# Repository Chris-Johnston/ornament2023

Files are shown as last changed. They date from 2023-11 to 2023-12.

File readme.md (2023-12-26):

# Xmas Ornament 2023

An ATTiny404 LED Xmas tree ornament.

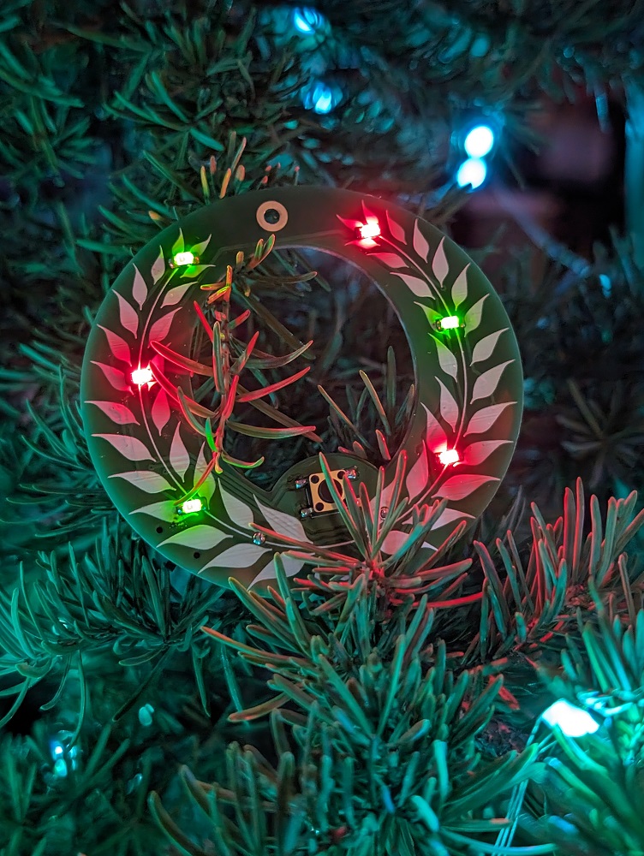
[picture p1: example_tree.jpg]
An image of the board in a tree


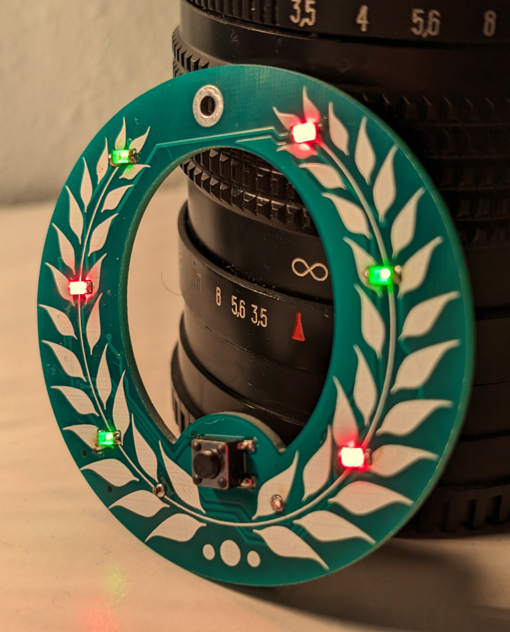
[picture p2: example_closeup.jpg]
Another image of the board closeup


This year I waited until the last minute,
[and so this design is very derivative of last year's design.](https://github.com/Chris-Johnston/ornament2022)

## Resources used

- [svg2mod] was used to generate the footprint of the board, and the front silkscreen layer
  - I licensed a stock image for the front layer silkscreen
- I referred to [SerialUPDI] again as reference for getting UPDI working (and used the same adapter board from last year, apparently I had swapped +5V and GND somehow!?)
- [megaTinyCore] was used with Arduino (via the vscode Arduino extension) to upload to the ATTiny404

[svg2mod]: https://github.com/svg2mod/svg2mod
[SerialUPDI]: https://teddywarner.org/Projects/SerialUPDI/
[megaTinyCore]: https://github.com/SpenceKonde/megaTinyCore

## Bill of Materials

| Reference | Description | Part No. | Price |
| --- | --- | --- | ----- |
| PCB | | | $0.53 (+ $0.80 shipping because I did this late) |
| C1 | 1 uf 1206 capacitor | CL31B105KAHNNNE | $0.0534 |
| D1 - D6 | 1206 Bidirectional Red/Green LED | XZMDKVG55W-4 | $1.10 (0.1835 ea.) |
| R1 - R6 | 1206 47 ohm resistor | WR12X470 JTL | $0.06 ($0.0112 ea.)
| SW1 | 6x6mm Pushbutton | Generic | $0.05 |
| SW2 | Slide Switch | JS102011SAQN | $0.65 |
| U1 | Attiny404 | Attiny404-SSN | $0.59 |
| B1 | CR2023 Battery Holder | BH-25C-1 | $0.0785 |

Unit cost w/o shipping: $3.11

## Changes from last year's version

In 2021 I made [snowflake-ornament] and [2022 I made a tree ornament.](https://github.com/Chris-Johnston/ornament2022) This year doesn't have
many changes, other than a different footprint and one less LED.

One less LED fits better with this board layout, and also means that
each common I/O between the left and right side can use PWM.
Despite this, I didn't actually have time to implement anything which
uses the PWM, I was finishing the code the same day I was supposed to drop these off.

Since this was so rushed, the board layout had a few quirks and features. All of the LEDs but ONE face the same orientation,
and the back isn't very symmetric.
For the most part it all worked though.

[snowflake-ornament]: https://github.com/Chris-Johnston/snowflake-ornament

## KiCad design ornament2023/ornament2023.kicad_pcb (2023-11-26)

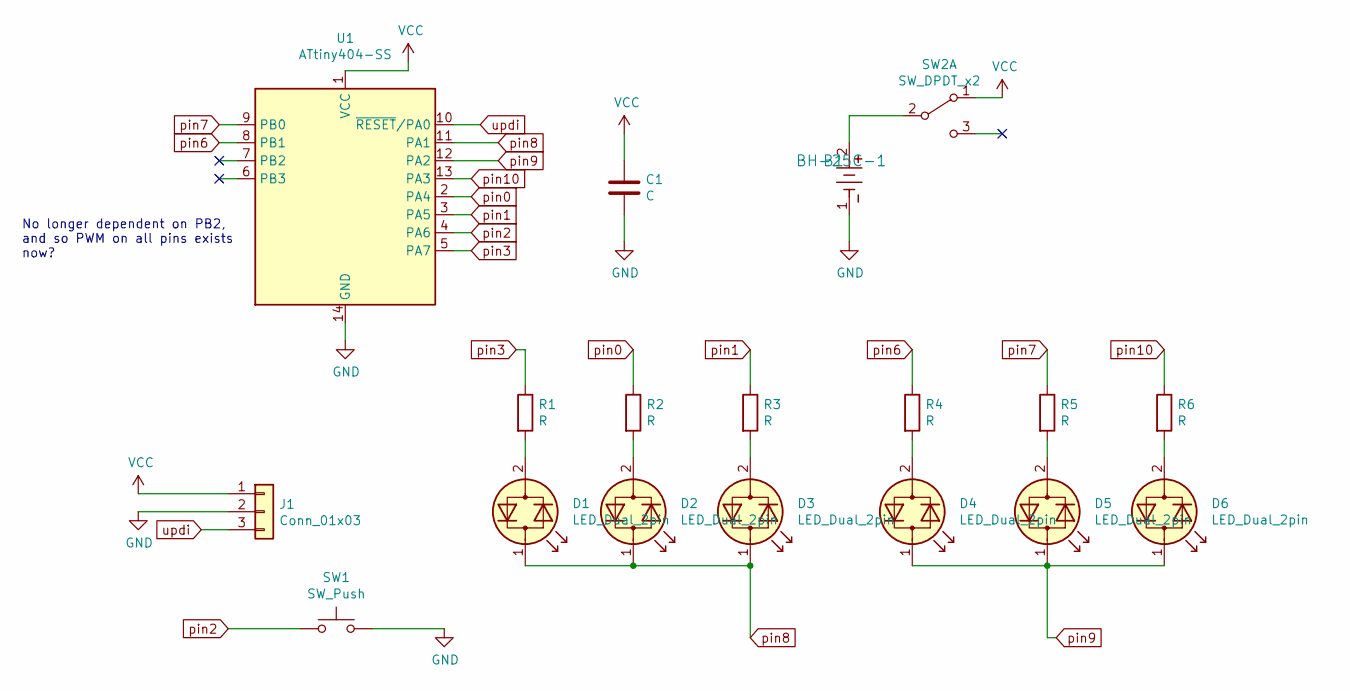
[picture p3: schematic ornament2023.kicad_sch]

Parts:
B1: BH-25C-1; BH-25C-1_ADM
C1: C; C_1206_3216Metric_Pad1.42x1.75mm_HandSolder
D1, D2, D3, D4, D5, D6: LED_Dual_2pin; Custom_LessSilkscreenLED_1206_3216Metric_Pad1.42x1.75mm_Han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
J1: Conn_01x03; custom_updipad_PinHeader_1x03_P2.54mm_Vertical
R1, R2, R3, R4, R5, R6: R; R_1206_3216Metric_Pad1.42x1.75mm_HandSolder
SW1: SW_Push; SW_Push_1P1T_NO_6x6mm_H9.5mm
SW2: SW_DPDT_x2; SW_SPDT_CK-JS102011SAQN
U1: ATtiny404-SS; SOIC-14_3.9x8.7mm_P1.27mm

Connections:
GND: B1.1, C1.2, J1.2, SW1.2, U1.14 (GND)
unnamed: D1.2 (AK), R1.2
unnamed: D2.2 (AK), R2.2
unnamed: D3.2 (AK), R3.2
unnamed: D4.2 (AK), R4.2
unnamed: D5.2 (AK), R5.2
unnamed: D6.2 (AK), R6.2
unnamed: B1.2, SW2.2 (B)
VCC: C1.1, J1.1, SW2.1 (A), U1.1 (VCC)
pin0: R2.1, U1.2 (PA4)
pin1: R3.1, U1.3 (PA5)
pin2: SW1.1, U1.4 (PA6)
pin3: R1.1, U1.5 (PA7)
pin6: R4.1, U1.8 (PB1)
pin7: R5.1, U1.9 (PB0)
pin8: D1.1 (KA), D2.1 (KA), D3.1 (KA), U1.11 (PA1)
pin9: D4.1 (KA), D5.1 (KA), D6.1 (KA), U1.12 (PA2)
pin10: R6.1, U1.13 (PA3)
updi: J1.3, U1.10 (~RESET/PA0)

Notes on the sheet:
No longer dependent on PB2, and so PWM on all pins exists now?

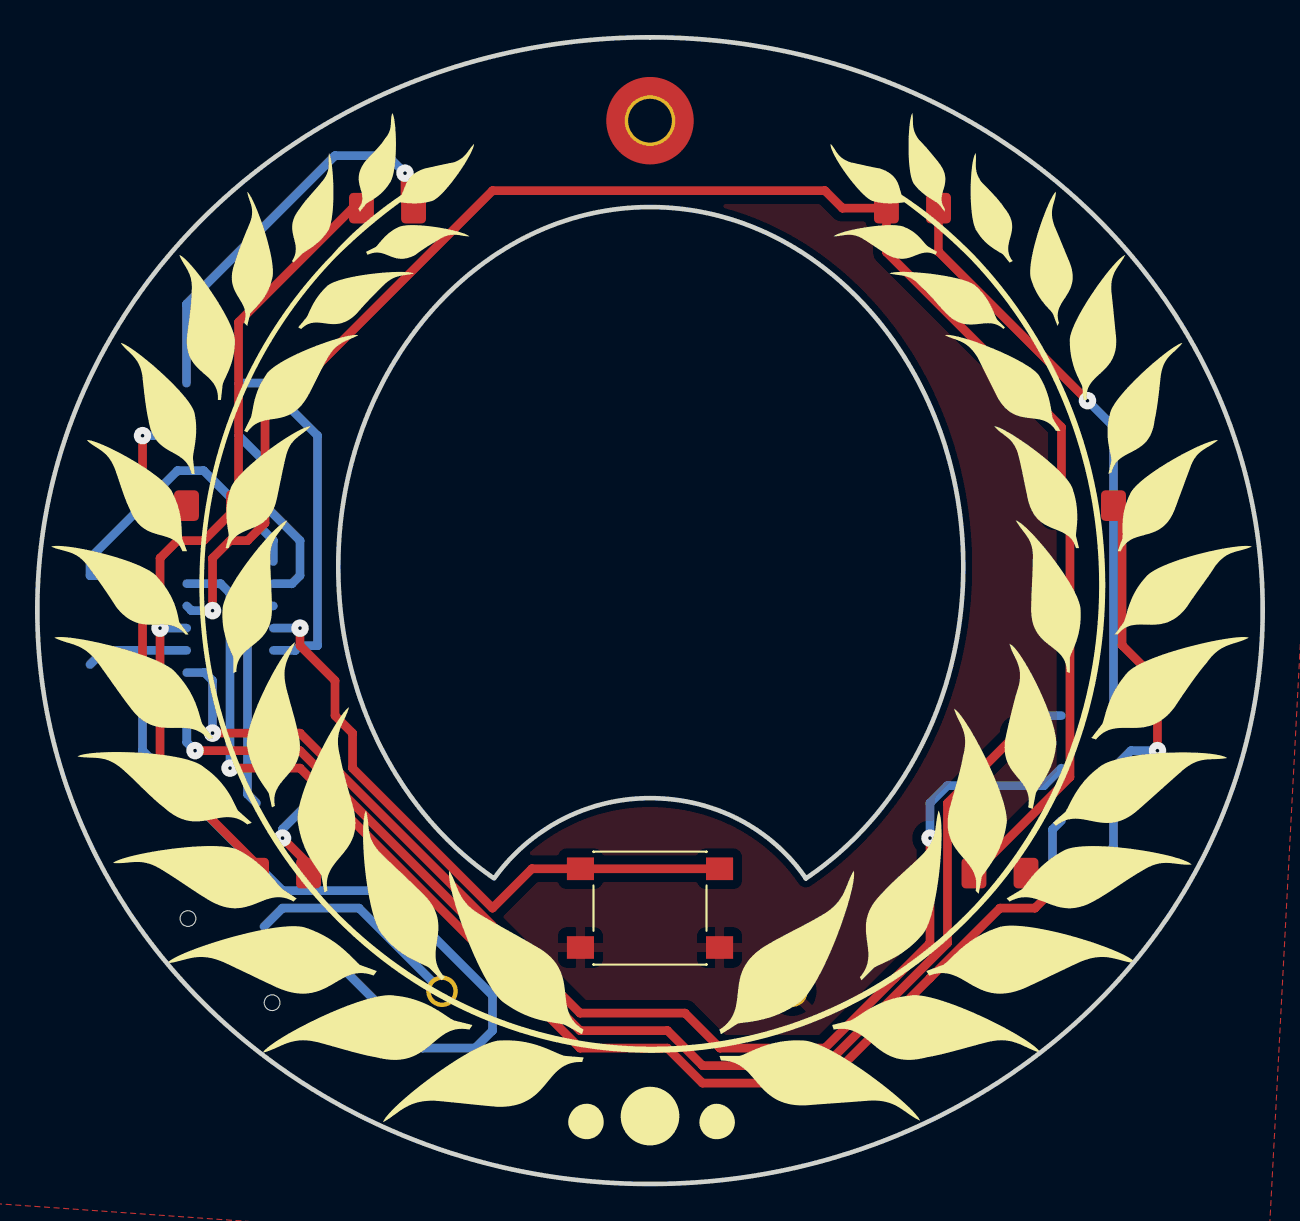
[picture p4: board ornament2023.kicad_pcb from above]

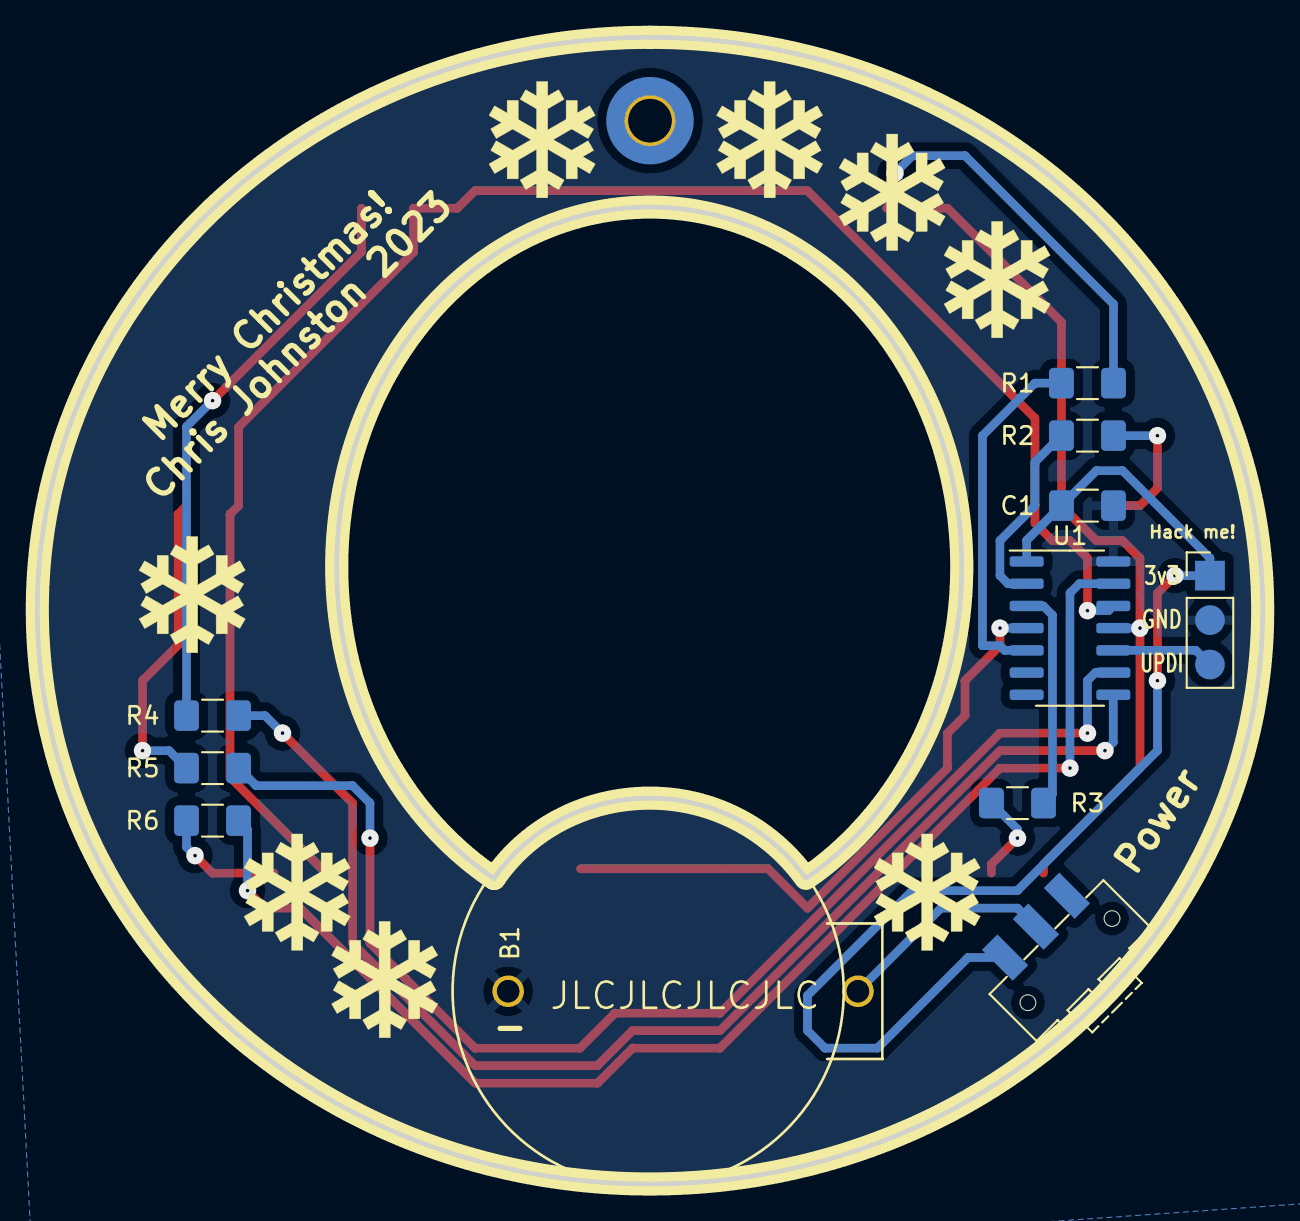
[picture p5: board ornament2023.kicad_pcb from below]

Board: 2 copper layers, 70.0 x 65.5 mm, 27 parts (19 on the bottom side), 19 nets.

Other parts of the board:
svg2mod: G***; wreath
svg2mod#2, svg2mod#3, svg2mod#4, svg2mod#5, svg2mod#6, svg2mod#7, svg2mod#8, svg2mod#9: G***; Snow_flake2

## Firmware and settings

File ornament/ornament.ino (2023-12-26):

// I never said this code wouldn't be messy.
// Merry Christmas.

#include <avr/io.h>
// #include <avr/iotn404.h>
#include <avr/interrupt.h>

int pinMin = 0;
int pinMax = 6;

// pinList - goes clockwise from the top
int pinlist[] = {
  // right side
  6, 7, 10,
  // left side
  1, 0, 3
};

int topCommon = 8; // left
int bottomCommon = 9; // right

// forward direction (0) is red (write 1 on pos)
// otherwise green
int topColor = 0;
int bottomColor = 0;

// pin with the button
int buttonIn = 2; // PA6
#define PIN_BUTTON 2
#define DEBOUNCE_TIME 150
#define NUM_PATTERNS 10

unsigned long lastDebounceTime = 0;
unsigned long button_debounce = 0;

int pattern = 0;

// the setup function runs once when you press reset or power the board
void setup() {
  // common
  pinMode(topCommon, OUTPUT);
  pinMode(bottomCommon, OUTPUT);

  for (int i = pinMin; i < pinMax; i++)
  {
    pinMode(pinlist[i], OUTPUT);
  }
  pinMode(buttonIn, INPUT_PULLUP);

  // enable PCINT0_vect for pin change
  PORTA.PIN6CTRL |= PORT_ISC_FALLING_gc;
}

// these show alternating colors
void xmascolors()
{
  int colorcycle = millis() / 1500 % 2;
  for (int p = 0; p < pinMax; p++)
  {
    digitalWrite(pinlist[p], (p + colorcycle) % 2 == 1);
  }

  // static
  // digitalWrite(topCommon, colorcycle);
  // digitalWrite(bottomCommon, colorcycle);

  // alternate the colors quickly
  for (int i = 0; i < 100; i++)
  {
    digitalWrite(topCommon, colorcycle);
    digitalWrite(bottomCommon, colorcycle);
    
    delay(1);

    digitalWrite(topCommon, 1 ^ colorcycle);
    digitalWrite(bottomCommon, 1 ^ colorcycle);

    delay(1);
  }
}

void loop()
{
  // handleDebounce();

  switch (pattern)
  {
    // case 0:
    //   // cycle();
    //   // off();
    //   break;
    // case 1:
    //   // too bright
    //   // topColor = 1;
    //   // bottomColor = 1;
    //   // solid();
    //   break;
    case 0:
      // testPattern();
      xmascolors();
      // wipeDown();
      // solid is tooo bright
      // topColor = 0;
      // bottomColor = 0;
      // solid();
      break;
    case 1:
      blonk();
      break;
    case 2:
      // may break if I end up using different resistors
      dimGreen();
      break;
    case 3:
      dimRed();
      break;
    case 4:
      orange();
      break;
    case 5:
      clockButNot();
      break;
    case 6:
      wipeDown();
      break;
    default:
      pattern = 0;
      break;
  }
}

ISR(PORTA_PORT_vect)
{
    // only update pattern if less than debounce time
    auto time = millis();
    if ((time - button_debounce) > DEBOUNCE_TIME)
    {
        pattern = (pattern + 1) % NUM_PATTERNS;

        button_debounce = millis();
    }

    // Have to manually clear the interrupt flag
    VPORTA.INTFLAGS |= (1 << 6);
}

void cycle() // too bright
{
  // cycle through the pwm pins randomly
  int pinIdx = random(1, pinMax);
  int color = random(1024) % 2;
  // int color = 0;
  bottomColor = color;
  topColor = color;

  off();

  for (int i = 0; i < 200; i+= 1)
  {
    analogWrite(pinlist[pinIdx], i);
    delay(1);
  }

  off();

  delay(50);
}

int wipeDownIdx = 0;
void wipeDown()
{
  {
    if (wipeDownIdx == 0)
    {
      bottomColor ^= 1;
    }
    topColor = bottomColor;
    off();
    
    digitalWrite(pinlist[wipeDownIdx], bottomColor ^ 1);
    // delayMicroseconds(1500);
    delay(10);
    off();
    delay(200);

    wipeDownIdx = (wipeDownIdx + 1) % pinMax;
  }
}

int getColor(int pin)
{
  if (pin == 6 || pin == 7 || pin == 10)
    {
      return bottomColor;
    }
  return topColor;
}

void blonk()
{
  // cycle through the pwm pins randomly
  int pinIdx = random(0, pinMax);
  int color = random(1024) % 2;
  // int color = 0;
  bottomColor = color;
  topColor = color;

  off();
  int pin = pinlist[pinIdx];
  digitalWrite(pin, color ^ 1);

  // delay(2);

  // maybe would want to tune this value based on battery? or color?
  // delayMicroseconds(3500 + random(200, 500));
  delay(random(2, 30));

  off();
  delay(200);
}

void dimGreen()
{
  topColor = 1;
  bottomColor = 1;
  solid();

  // auto buh = 50;
  // for (int i = 0; i < 100; i++)
  // {
  //   // PORTA.OUTSET = 0b00000110;
  //   PORTA.OUTTGL = 0b00000110;
  //   delayMicroseconds(69);
  //   // // PORTA.OUTCLR = 0b00000110;
  //   // PORTA.OUTTGL = 0b00000110;
  //   // delayMicroseconds(1);
  // }
}

void testPattern()
{
  topColor = 1; 
  bottomColor = 1;
  solid();

  delay(300);

  topColor = 0; 
  bottomColor = 0;
  solid();

  delay(300);

  off();

  for (int i = 0; i < pinMax; i++)
  {
    digitalWrite(pinlist[i], 1);
    delay(200);
  }

  topColor = 1;
  bottomColor = 1;
  off();

  for (int i = 0; i < pinMax; i++)
  {
    digitalWrite(pinlist[i], 0);
    delay(200);
  }

  off();
  delay(200);
}

void dimRed()
{
  topColor = 0;
  bottomColor = 0;
  solid();

  // auto buh = 50;
  // for (int i = 0; i < 100; i++)
  // {
  //   // PORTA.OUTSET = 0b00000110;
  //   PORTA.OUTTGL = 0b00000110;
  //   delayMicroseconds(69);
  //   // PORTA.OUTCLR = 0b00000110;
  //   PORTA.OUTTGL = 0b00000110;
  //   delayMicroseconds(1);
  // }
}

void orange()
{
  topColor = 0;
  bottomColor = 0;
  // solid();

  auto buh = 50;
  for (int i = 0; i < 100; i++)
  {
    topColor = topColor ^ 1;
    bottomColor = bottomColor ^ 1;
    solid();
    delayMicroseconds(1);
    // delay(1);
    // PORTA.OUTSET = 0b00000110;
    PORTA.OUTTGL = 0b00000110;
    delayMicroseconds(20);
    // PORTA.OUTCLR = 0b00000110;
    // PORTA.OUTTGL = 0b00000110;
    // delayMicroseconds(1);
  }
}

void off()
{

// 3, 1, 0, 5
// PA7, PA5, PA4, PB2
// 6, 7, 10
// PB1, PB0, PA3
// 8, 9
// PA1, PA2

  // 7 5 4
  int topa_mask = 0b10110000;
  // pb2
  int topb_mask = 0b00000100;

  int bottoma_mask = 0b00001000;
  int bottomb_mask = 0b00000011;

  uint8_t portaTemp = (topColor & 1) << 1 | (bottomColor & 1) << 2;
  uint8_t portbTemp = 0;

  if (topColor)
  {
    // if top color is on
    portaTemp |= topa_mask;
    portbTemp |= topb_mask;
  }
  if (bottomColor)
  {
    // if top color is on
    portaTemp |= bottoma_mask;
    portbTemp |= bottomb_mask;
  }

  PORTA.OUT = portaTemp;
  PORTB.OUT = portbTemp;

  // PORTA = 0b00000000;
  // PORTB = 0b00000000;
  // iotn404.h
  // PORTA.OUTCLR = 0b11111001 | (topColor ^ 1 << 1) | (bottomColor ^ 1 << 2);
  //PORTA.OUT = 0 | ((topColor & 1) << 1) | ((bottomColor & 1) << 2);
  // PORTA.OUT = 0;
  // PORTB.OUTCLR = 0b11111111;

  // quickly turn off pwm
  TCA0.SPLIT.CTRLB = 0;
  // PORTB.OUT = 0;

  // slow
  // PORTA = 0;




  // digitalWrite(topCommon, topColor ^ 1);
  // for (int i = 0; i < 4; i++)
  // {
  //   digitalWrite(pinlist[i], topColor ^ 1);
  // }
  // digitalWrite(bottomCommon, bottomColor ^ 1);
  // for (int i = 4; i < pinMax; i++)
  // {
  //   digitalWrite(pinlist[i], bottomColor ^ 1);
  // }
}

void clockButNot()
{
  int seconds = millis() / 1000;

  topColor = (millis() / 30000) % 2;

  // if (seconds % 100 == 0)
  // {
  //   topColor ^= 1;
  //   iters = 1000;
  // }
  bottomColor = topColor;

  off();

  seconds = seconds & 0b1111111;
  for (int i = 0; i < pinMax; i++)
  {
    digitalWrite(pinlist[i], topColor ^ ((seconds & (1 << i)) >> i));
  }

  // uint8_t portaToggle = PORTA.OUT;
  // uint8_t portbToggle = PORTB.OUT;
  
  // for (int i = 0; i < 100; i++)
  // {
  //   off();
  //   delayMicroseconds(90);

  //   PORTA.OUT = portaToggle;
  //   PORTB.OUT = portbToggle;
  //   delayMicroseconds(10);
  // }

  
}



void solid()
{
  int topa_mask = 0b10110000;
  // pb2
  int topb_mask = 0b00000100;

  int bottoma_mask = 0b00001000;
  int bottomb_mask = 0b00000011;

  // common mask
  // int commona_mask = 0b110;

  uint8_t portaTemp = (topColor & 1) << 1 | (bottomColor & 1) << 2;
  uint8_t portbTemp = 0;

  if (!topColor)
  {
    // if top color is on
    portaTemp |= topa_mask;
    portbTemp |= topb_mask;
  }
  if (!bottomColor)
  {
    // if top color is on
    portaTemp |= bottoma_mask;
    portbTemp |= bottomb_mask;
  }

  PORTA.OUT = portaTemp;
  PORTB.OUT = portbTemp;


  // digitalWrite(topCommon, topColor ^ 1);
  // digitalWrite(bottomCommon, bottomColor ^ 1);

  // for (int i = 0; i < 4; i++)
  // {
  //   digitalWrite(pinlist[i], topColor);
  // }
  // for (int i = 4; i < 7; i++)
  // {
  //   digitalWrite(pinlist[i], bottomColor);
  // }
}

// int a = 0;

// the loop function runs over and over again forever
// void loop() {

//   if (!digitalRead(buttonIn))
//   {
//    a = a ^ 1;
//    delay(100); 
//   }

//   // toggle color
//   digitalWrite(8, a);
//   digitalWrite(9, a);

//   // zero states
//   for (int i = pinMin; i < pinMax; i++)
//   {
//     digitalWrite(pinlist[i], a );
//   }
  
//     auto pressed = !digitalRead(buttonIn);
//     // digitalWrite(0, pressed);

//     // return;

//   for (int i = pinMin; i < pinMax; i++)
//   {
// //    for (int x = 0; x < 50; x+=5)
// //    {
// //      analogWrite(pinlist[i], x);
// //      delay(10);
// //    }
// digitalWrite(pinlist[i], a ^ 1);
// delay(0);
//    // digitalWrite(pinlist[i], HIGH);   // turn the LED on (HIGH is the voltage level)
//   // delay(100);                       // wait for a second
//   // digitalWrite(pinlist[i], a);    // turn the LED off by making the voltage LOW
//   delay(0);                       // wait for a second 
//   }
// }

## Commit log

2023-11-26 kinda just sat down and did this all in one go
    [ornament2023.kicad_pcb, ornament2023.kicad_sch]
2023-12-24 add arduino settings
